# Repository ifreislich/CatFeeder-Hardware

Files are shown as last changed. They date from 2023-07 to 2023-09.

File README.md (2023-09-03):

# CatFeeder-Hardware

The control board for the Cat Feeder project.  For completion you will need both
[CatFeeder Firmware](https://github.com/ifreislich/CatFeeder-Firmware)
and
[Catfeeder Enclosure](https://github.com/ifreislich/CatFeeder-3D-Model).

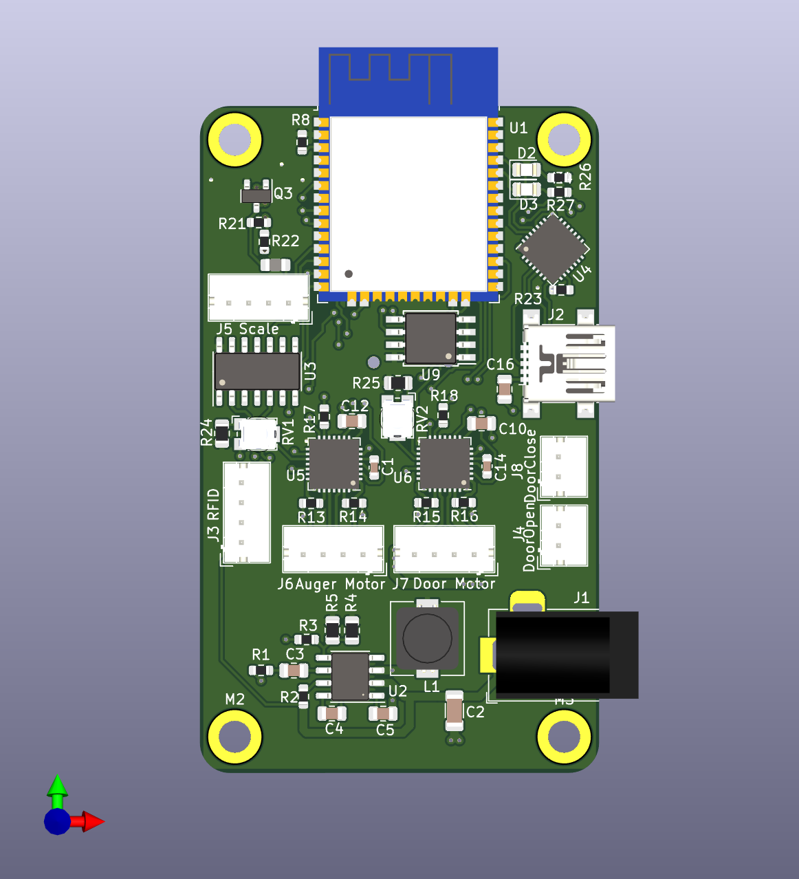
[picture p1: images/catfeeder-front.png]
CatFeeder-Hardware


## Wiring
J3 RFID - Wire from HID 5365EGP00 or similar 
Pin|Signal|Wire
---|------|------
1|+12V|Red
2|Data 1|White
3|Data 0|Green
4|GND|Black

J5 Scale - Connection to the Load Cell
Pin|Wire
---|----
1|Black
2|Red
3|Green
4|White

J6 Auger - Nema17 20mm stepper motor
Pin|Signal|Wire
---|------|----
1|2B|Black
2|2A|Green
3|1A|Red
4|1B|Blue

J7 Door - 28BYJ-48 Stepper motor
Pin|Signal|Wire
---|------|----
1|2B|Blue
2|2A|Yellow
3|1A|Pink
4|1B|Orange

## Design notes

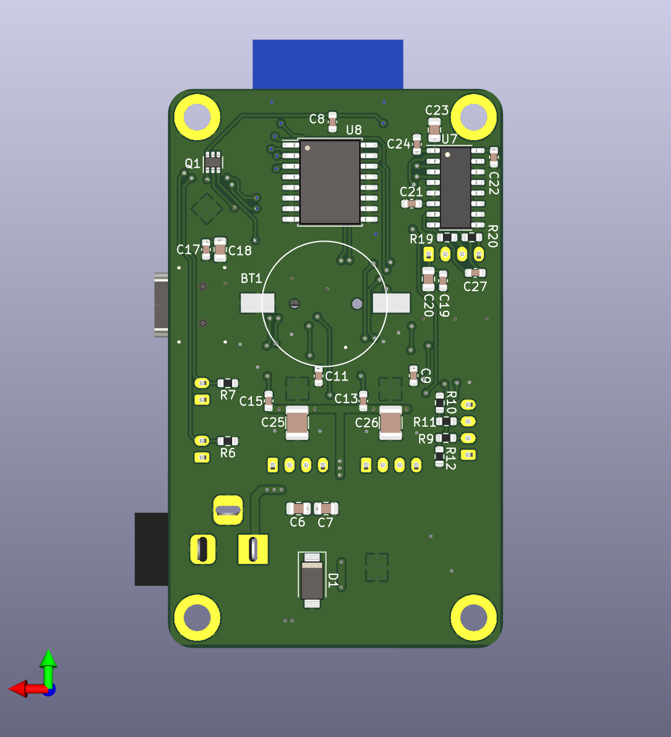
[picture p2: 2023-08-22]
images/catfeeder-back.png

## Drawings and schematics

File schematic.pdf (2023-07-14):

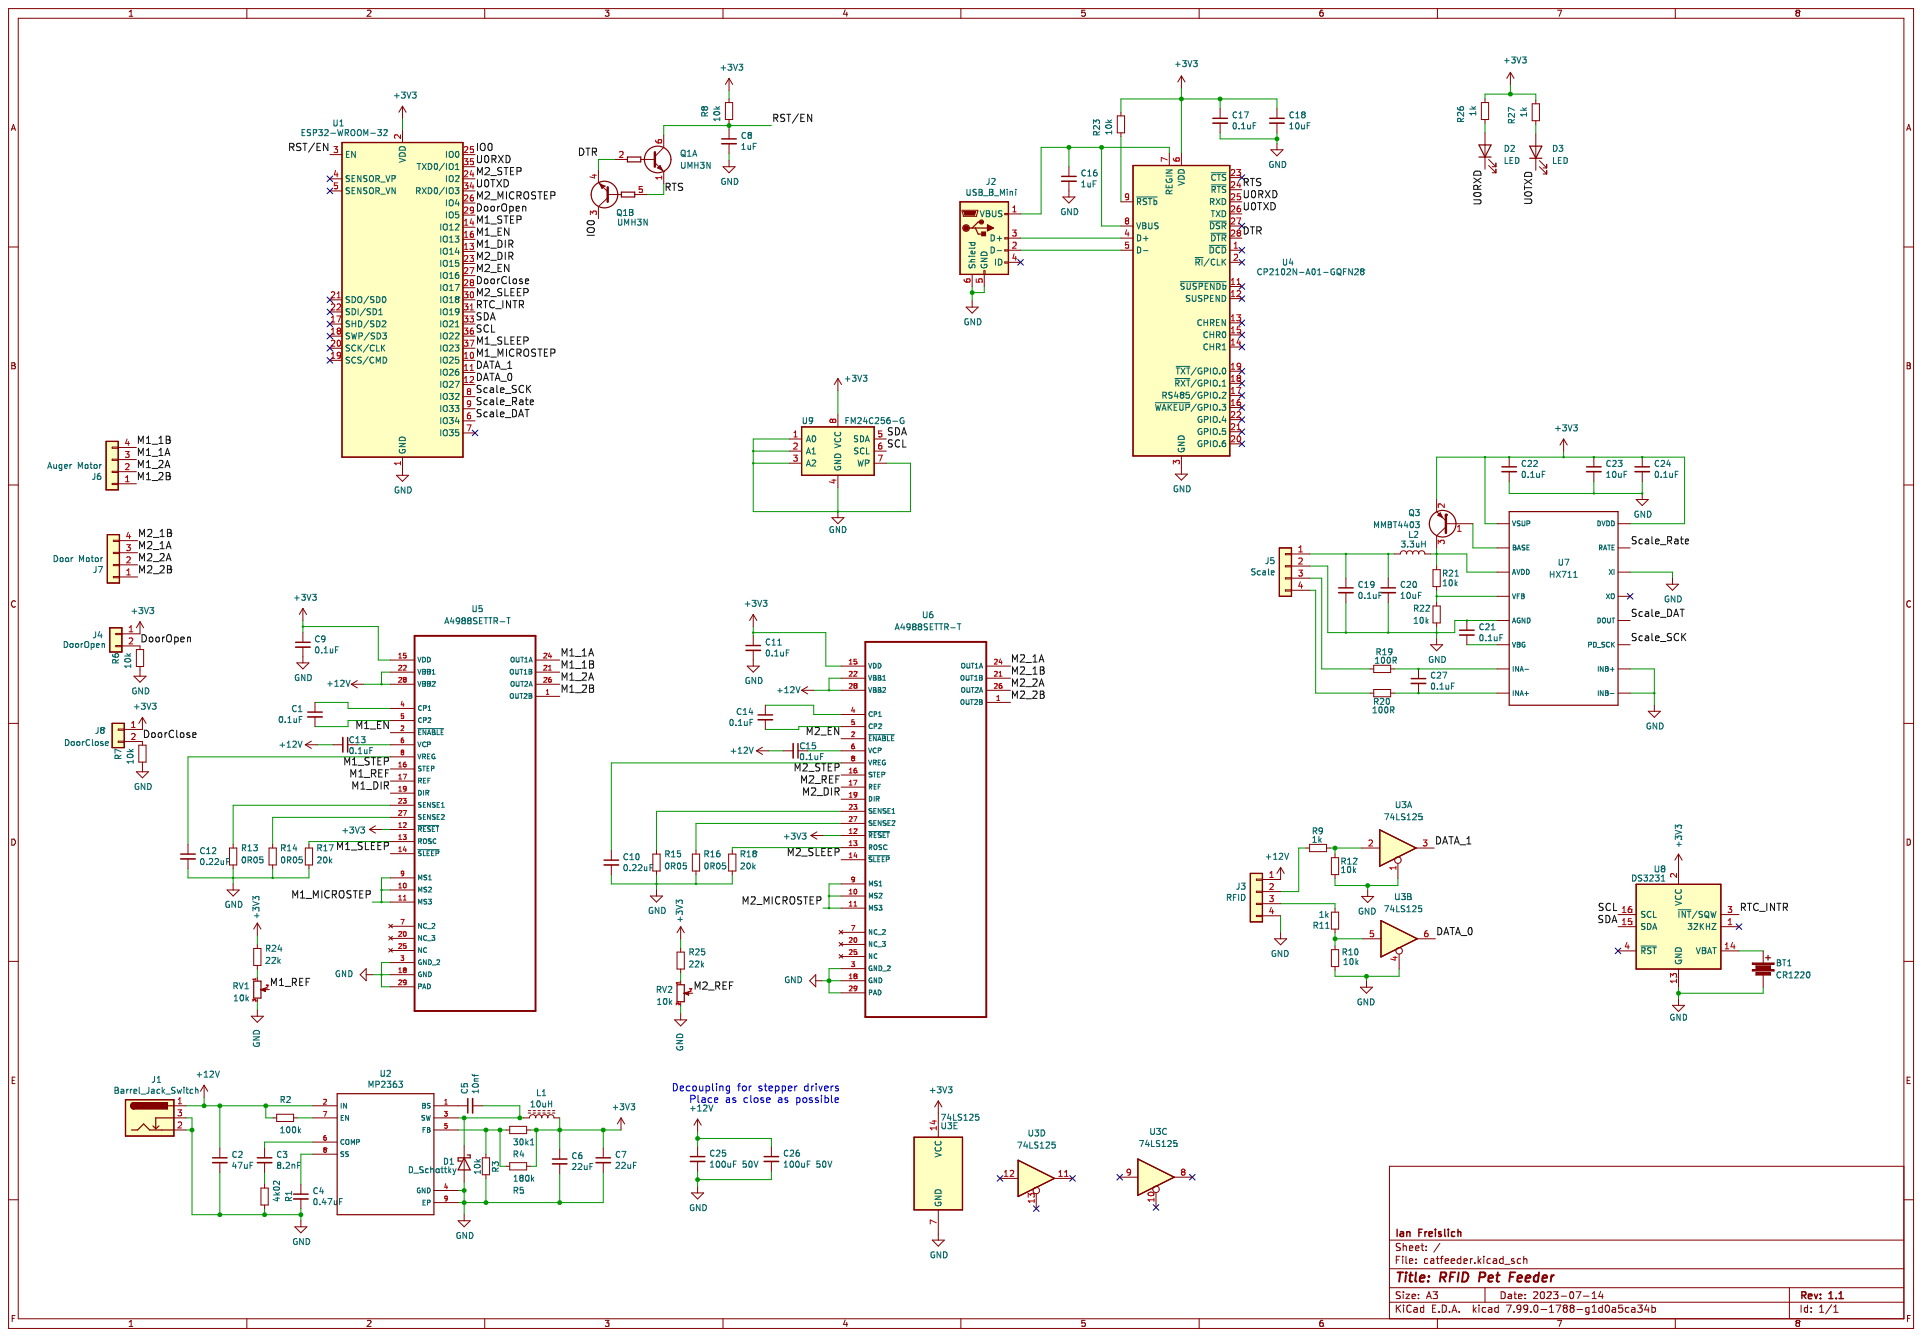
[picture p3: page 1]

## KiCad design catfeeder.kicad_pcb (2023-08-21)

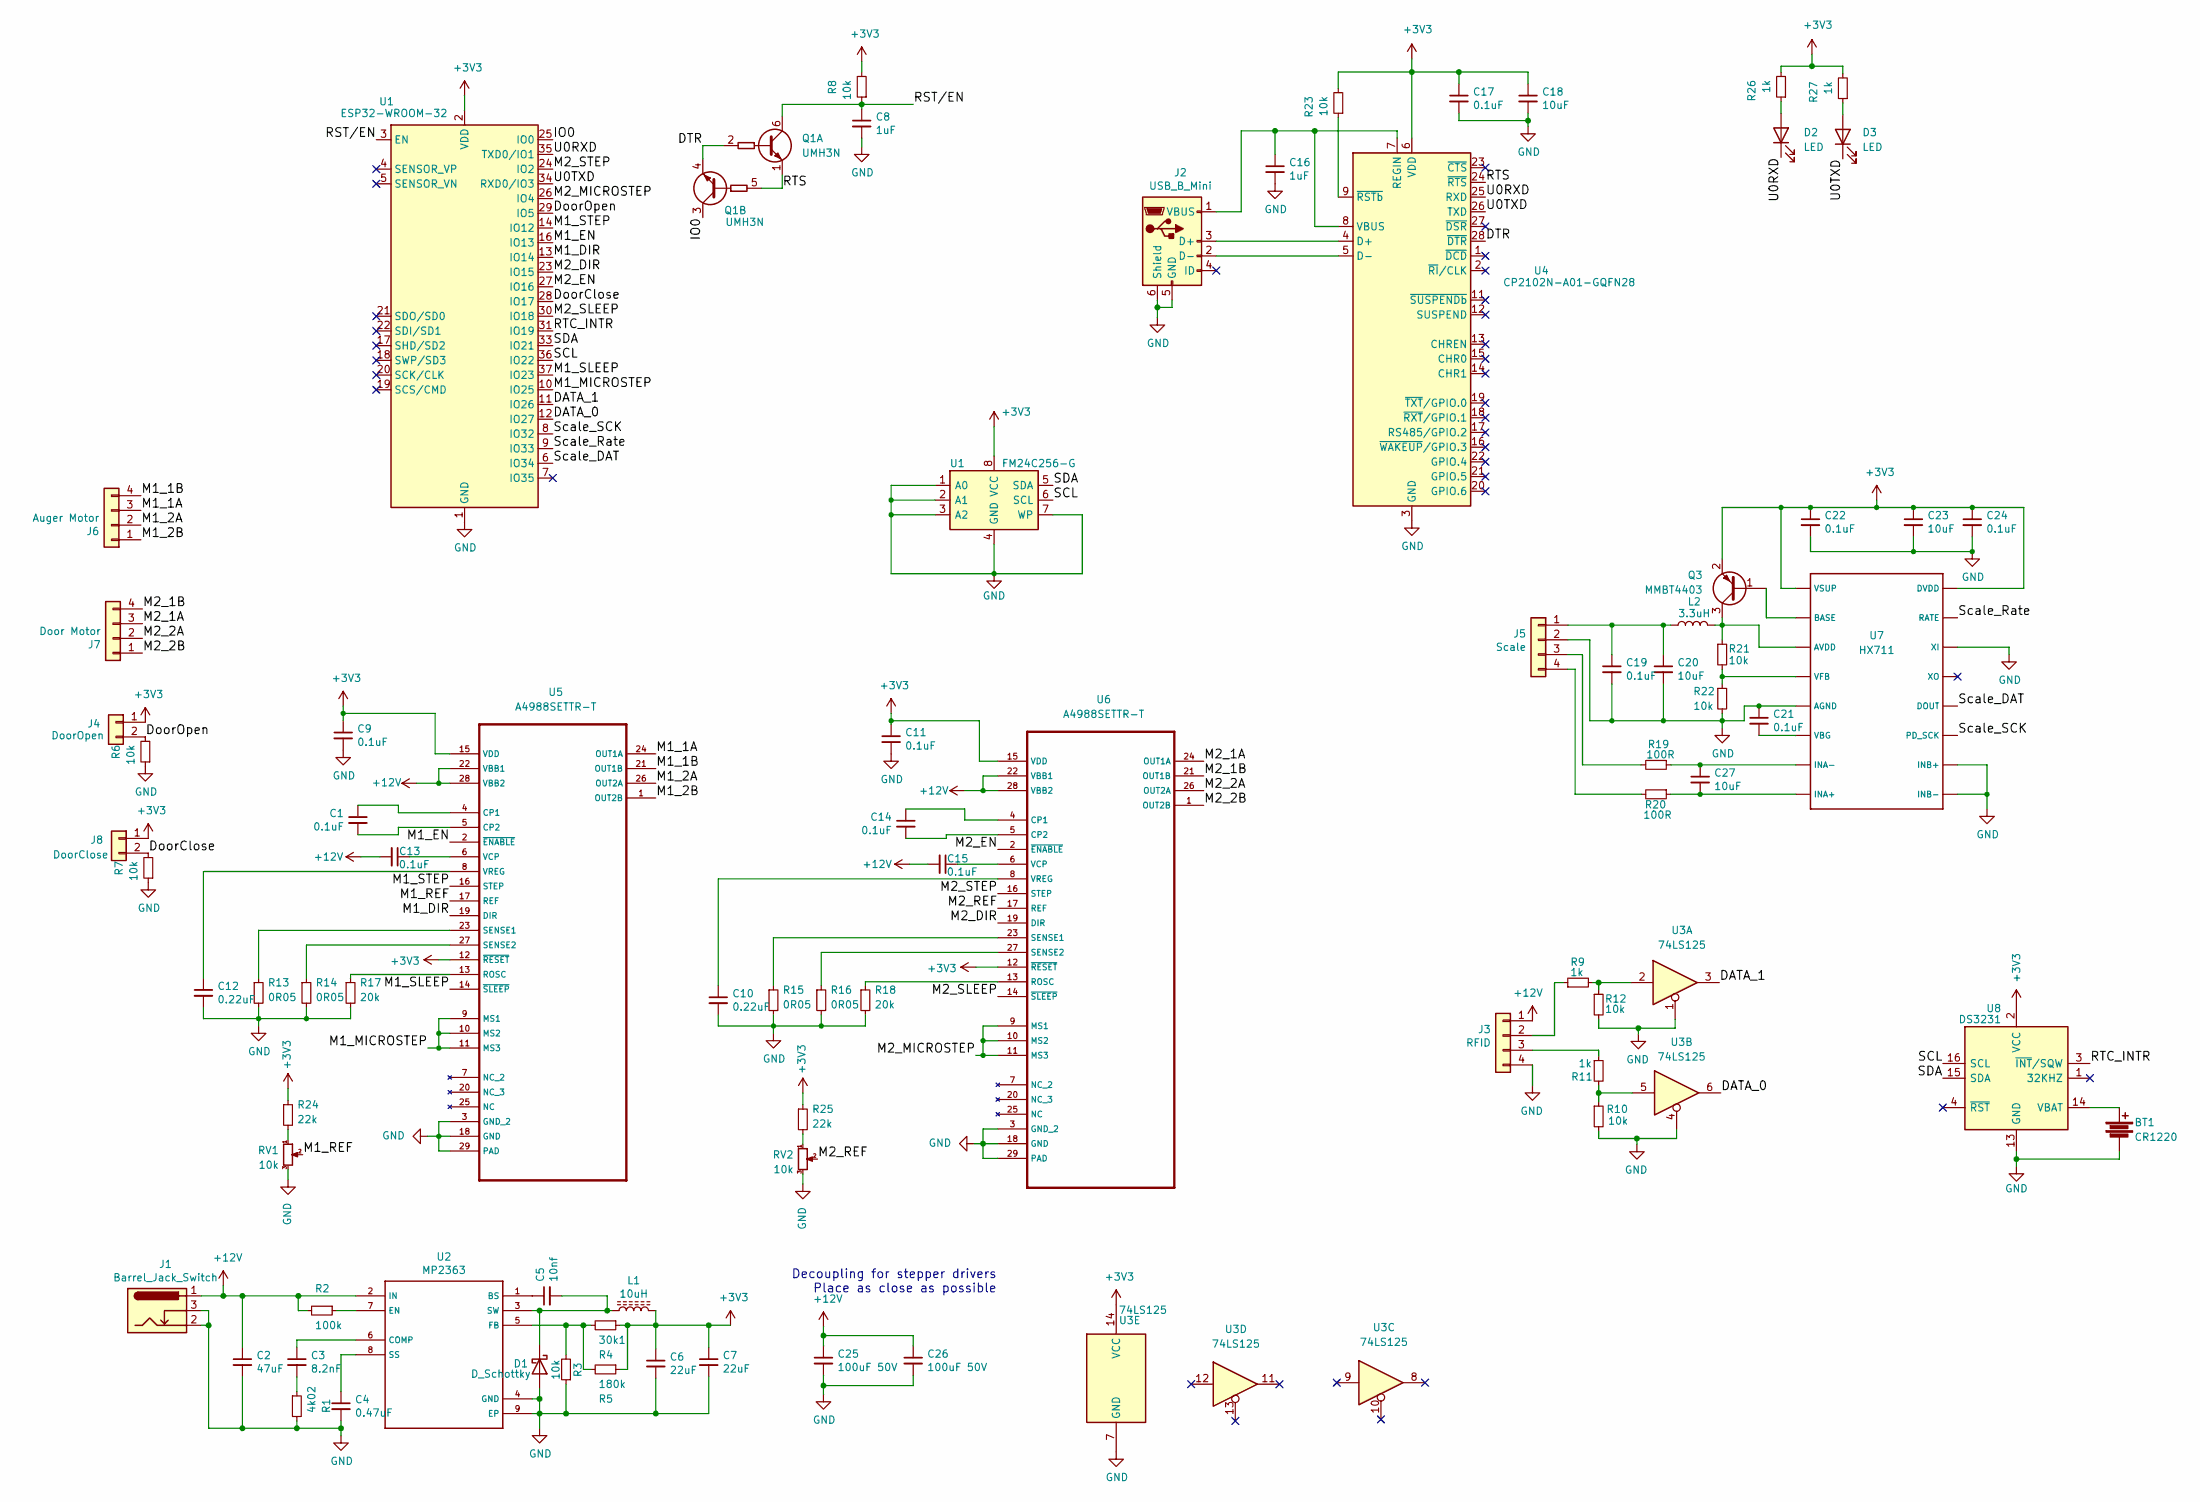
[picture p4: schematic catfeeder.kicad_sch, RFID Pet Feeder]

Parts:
BT1: CR1220; CR1220SMD
C1, C9, C11, C13, C14, C15, C17, C19, C21, C22, C24: 0.1uF; C_0603_1608Metric
C2: 47uF; C_1206_3216Metric
C3: 8.2nF; C_0805_2012Metric
C4: 0.47uF; C_0805_2012Metric
C5: 10nf; C_0805_2012Metric
C6, C7: 22uF; C_0805_2012Metric
C8: 1uF; C_0603_1608Metric
C10, C12: 0.22uF; C_0805_2012Metric
C16: 1uF; C_0805_2012Metric
C18, C20, C23: 10uF; C_0805_2012Metric
C25, C26: 100uF 50V; C_1210_3225Metric
C27: 10uF; C_0603_1608Metric
D1: D_Schottky; D_SMA
D2, D3: LED; LED_0805_2012Metric
J1: Barrel_Jack_Switch; BarrelJack_Horizontal
J2: USB_B_Mini; USB_Mini-B_Lumberg_2486_01_Horizontal
J3: RFID; JST_PH_B4B-PH-K_1x04_P2.00mm_Vertical
J4: DoorOpen; JST_PH_B2B-PH-K_1x02_P2.00mm_Vertical
J5: Scale; JST_PH_B4B-PH-K_1x04_P2.00mm_Vertical
J6: Auger Motor; JST_PH_B4B-PH-K_1x04_P2.00mm_Vertical
J7: Door Motor; JST_PH_B4B-PH-K_1x04_P2.00mm_Vertical
J8: DoorClose; JST_PH_B2B-PH-K_1x02_P2.00mm_Vertical
L1: 10uH; L_7.3x7.3_H3.5
L2: 3.3uH; L_0805_2012Metric
Q1: UMH3N; SOT-363_SC-70-6
Q3: MMBT4403; SOT-23
R1: 4k02; R_0603_1608Metric
R2: 100k; R_0603_1608Metric
R3, R6, R7, R8, R10, R12, R21, R22, R23: 10k; R_0603_1608Metric
R4: 30k1; R_0805_2012Metric
R5: 180k; R_0805_2012Metric
R9, R11, R26, R27: 1k; R_0603_1608Metric
R13, R14, R15, R16: 0R05; R_0603_1608Metric
R17, R18: 20k; R_0603_1608Metric
R19, R20: 100R; R_0603_1608Metric
R24, R25: 22k; R_0805_2012Metric
RV1, RV2: 10k; Potentiometer_Bourns_TC33X_Vertical
U1: ESP32-WROOM-32
U2: MP2363; HSOP-8-1EP_3.9x4.9mm_P1.27mm_EP2.41x3.1mm_ThermalVias
U3: 74LS125; SOIC-14_3.9x8.7mm_P1.27mm
U4: CP2102N-A01-GQFN28; QFN-28-1EP_5x5mm_P0.5mm_EP3.35x3.35mm_ThermalVias
U5, U6: A4988SETTR-T; QFN-28-1EP_5x5mm_P0.5mm_EP3.35x3.35mm_ThermalVias
U7: HX711; SO-16_3.9x9.9mm_P1.27mm
U8: DS3231; SOIC-16W_7.5x10.3mm_P1.27mm

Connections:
+12V: C2.1, C13.2, C15.2, C25.1, C26.1, J1.1, J3.1, R2.2, U2.2 (IN), U5.22 (VBB1), U5.28 (VBB2), U6.22 (VBB1), U6.28 (VBB2)
/DATA_0: U1.12 (IO27), U3.6
/DATA_1: U1.11 (IO26), U3.3
/DTR: Q1.2 (B1), Q1.4 (E2), U4.28 (~DTR)
/DoorClose: J8.2, R7.2, U1.28 (IO17)
/DoorOpen: J4.2, R6.2, U1.29 (IO5)
/IO0: Q1.3 (C2), U1.25 (IO0)
/M1_1A: J6.3, U5.24 (OUT1A)
/M1_1B: J6.4, U5.21 (OUT1B)
/M1_2A: J6.2, U5.26 (OUT2A)
/M1_2B: J6.1, U5.1 (OUT2B)
/M1_DIR: U1.13 (IO14), U5.19 (DIR)
/M1_EN: U1.16 (IO13), U5.2 (~ENABLE)
/M1_MICROSTEP: U1.10 (IO25), U5.9 (MS1), U5.10 (MS2), U5.11 (MS3)
/M1_REF: RV1.2, U5.17 (REF)
/M1_SLEEP: U1.37 (IO23), U5.14 (~SLEEP)
/M1_STEP: U1.14 (IO12), U5.16 (STEP)
/M2_1A: J7.3, U6.24 (OUT1A)
/M2_1B: J7.4, U6.21 (OUT1B)
/M2_2A: J7.2, U6.26 (OUT2A)
/M2_2B: J7.1, U6.1 (OUT2B)
/M2_DIR: U1.23 (IO15), U6.19 (DIR)
/M2_EN: U1.27 (IO16), U6.2 (~ENABLE)
/M2_MICROSTEP: U1.26 (IO4), U6.9 (MS1), U6.10 (MS2), U6.11 (MS3)
/M2_REF: RV2.2, U6.17 (REF)
/M2_SLEEP: U1.30 (IO18), U6.14 (~SLEEP)
/M2_STEP: U1.24 (IO2), U6.16 (STEP)
/RTC_INTR: U1.31 (IO19), U8.3 (~INT/SQW)
/RTS: Q1.1 (E1), Q1.5 (B2), U4.24 (~RTS)
/SDA: U1.5 (SDA), U1.33 (IO21), U8.15 (SDA); also elsewhere on the board
/Scale_Rate: U1.9 (IO33), U7.15 (RATE)
/U0RXD: D2.1 (K), U1.35 (TXD0/IO1), U4.25 (RXD)
/U0TXD: D3.1 (K), U1.34 (RXD0/IO3), U4.26 (TXD)
unnamed: C3.2, R1.1
unnamed: C5.2, D1.1 (K), L1.1, U2.3 (SW)
unnamed: D2.2 (A), R26.1
unnamed: D3.2 (A), R27.1
unnamed: J2.3 (D+), U4.4 (D+)
unnamed: J2.2 (D-), U4.5 (D-)
unnamed: C16.1, J2.1 (VBUS), U4.7 (REGIN), U4.8 (VBUS)
unnamed: J3.2, R9.1
unnamed: J3.3, R11.1
unnamed: C19.1, C20.1, J5.1, L2.1
unnamed: J5.3, R19.2
unnamed: J5.4, R20.2
unnamed: Q3.1 (B), U7.2 (BASE)
unnamed: L2.2, Q3.3 (C), R21.1, U7.3 (AVDD)
unnamed: R10.1, R11.2, U3.5
unnamed: R9.2, R12.1, U3.2
unnamed: R24.2, RV1.1
unnamed: R25.2, RV2.1
unnamed: C5.1, U2.1 (BS)
unnamed: C3.1, U2.6 (COMP)
unnamed: R2.1, U2.7 (EN)
unnamed: R3.2, R4.2, R5.2, U2.5 (FB)
unnamed: C4.1, U2.8 (SS)
unnamed: R23.1, U4.9 (~RSTb)
unnamed: C1.1, U5.4 (CP1)
unnamed: C1.2, U5.5 (CP2)
unnamed: R17.1, U5.13 (ROSC)
unnamed: R13.1, U5.23 (SENSE1)
unnamed: R14.1, U5.27 (SENSE2)
unnamed: C13.1, U5.6 (VCP)
unnamed: C12.1, U5.8 (VREG)
unnamed: C14.1, U6.4 (CP1)
unnamed: C14.2, U6.5 (CP2)
unnamed: R18.1, U6.13 (ROSC)
unnamed: R15.1, U6.23 (SENSE1)
unnamed: R16.1, U6.27 (SENSE2)
unnamed: C15.1, U6.6 (VCP)
unnamed: C10.1, U6.8 (VREG)
unnamed: C27.2, R20.1, U7.8 (INA+)
unnamed: C27.1, R19.1, U7.7 (INA-)
unnamed: C21.2, U7.6 (VBG)
unnamed: R21.2, R22.1, U7.4 (VFB)
unnamed: BT1.1, U8.14 (VBAT)

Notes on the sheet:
Decoupling for stepper drivers Place as close as possible

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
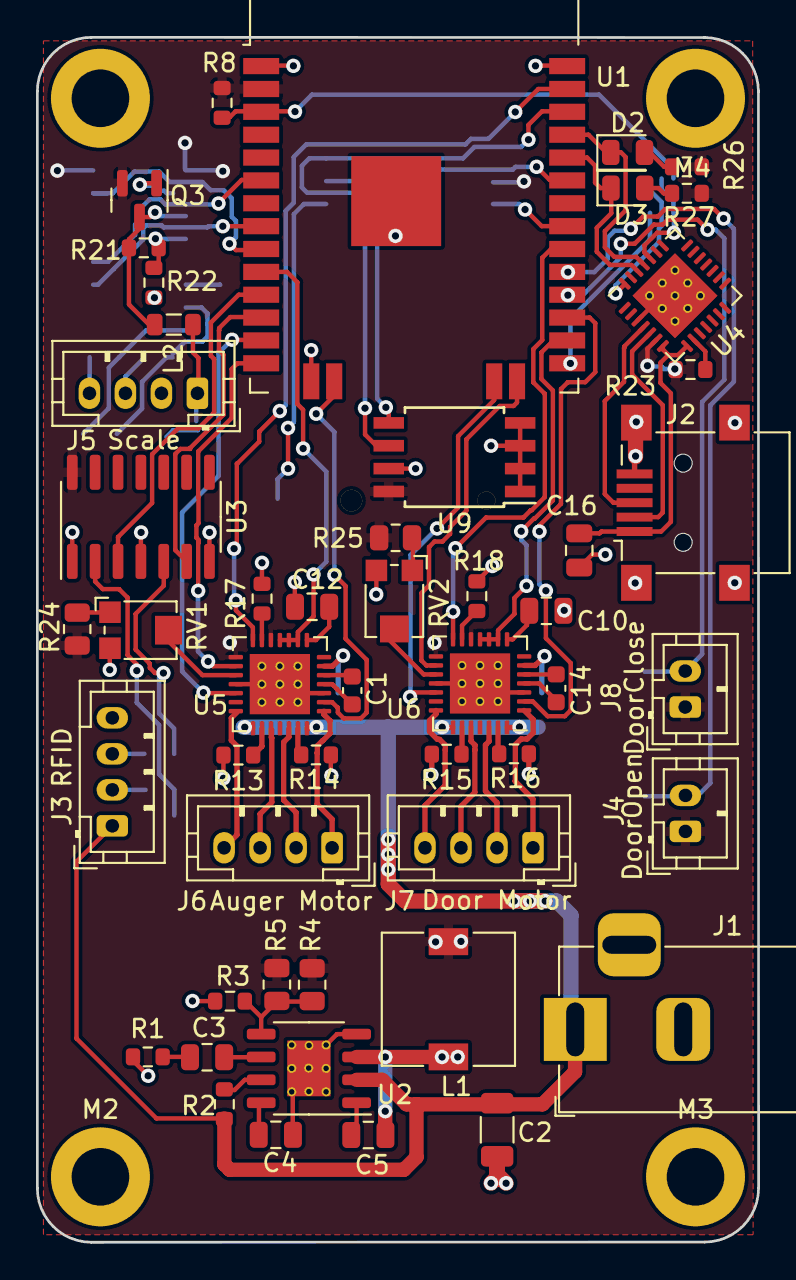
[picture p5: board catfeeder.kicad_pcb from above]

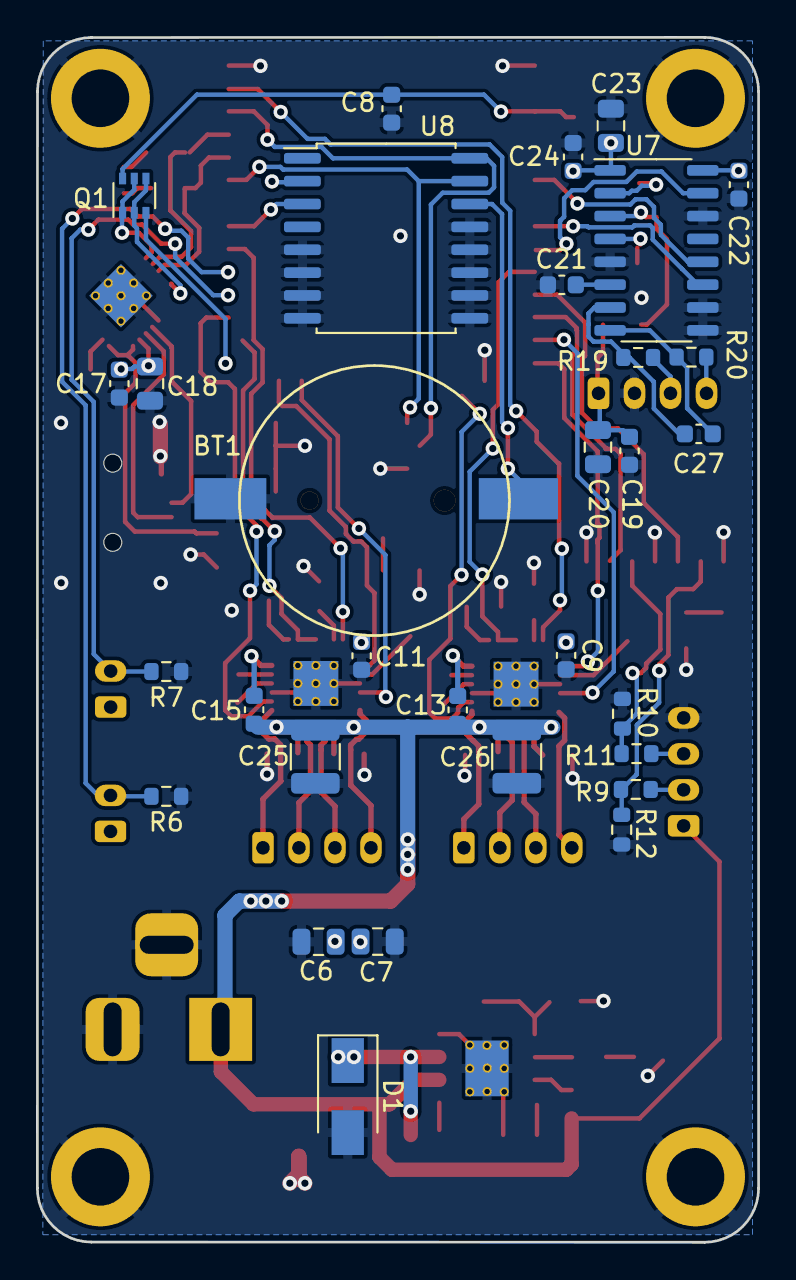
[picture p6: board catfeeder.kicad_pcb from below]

Board: 2 copper layers, 40.1 x 66.9 mm, 85 parts (31 on the bottom side), 82 nets.

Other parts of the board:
M1, M2, M3, M4: Mount; MountingHole_3.2mm_M3_ISO14580_Pad
U9: FM24C256-G; SOIC-8W_5.3x5.3mm_P1.27mm

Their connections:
/SDA: U9.5 (SDA); also elsewhere on the board

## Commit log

2023-07-12 Add renders of the board front and back.
2023-07-12 Cleanup tracks and vias.
    [catfeeder.kicad_pcb]
2023-07-14 Add a PDF of the schematic
2023-07-14 Update the page title and revision.
    [catfeeder.kicad_pcb, catfeeder.kicad_sch]
2023-08-21 Save with new KiCAD version. Cleanup some tracks and vias.
    [catfeeder.kicad_pcb, catfeeder.kicad_sch]
2023-08-22 Re-generate the image because one of the connectors was highlighted.
2023-08-22 Regenerate again to remove the connector highlight.
